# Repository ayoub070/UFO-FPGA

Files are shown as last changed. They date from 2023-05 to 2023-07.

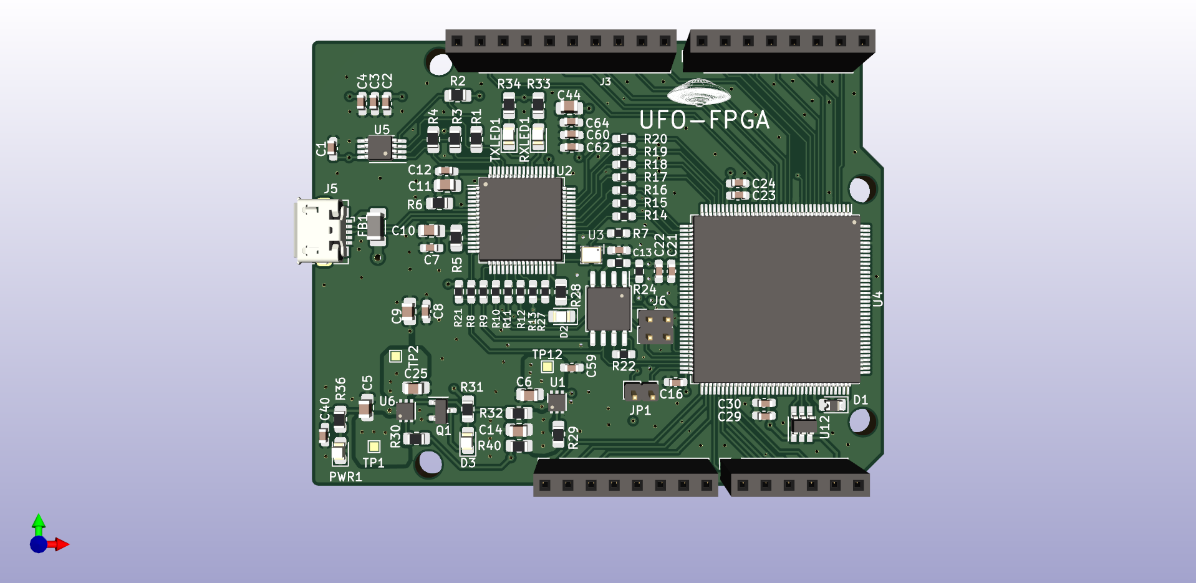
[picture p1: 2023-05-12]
UFO-FPGA/UFO-FPGA-2.png

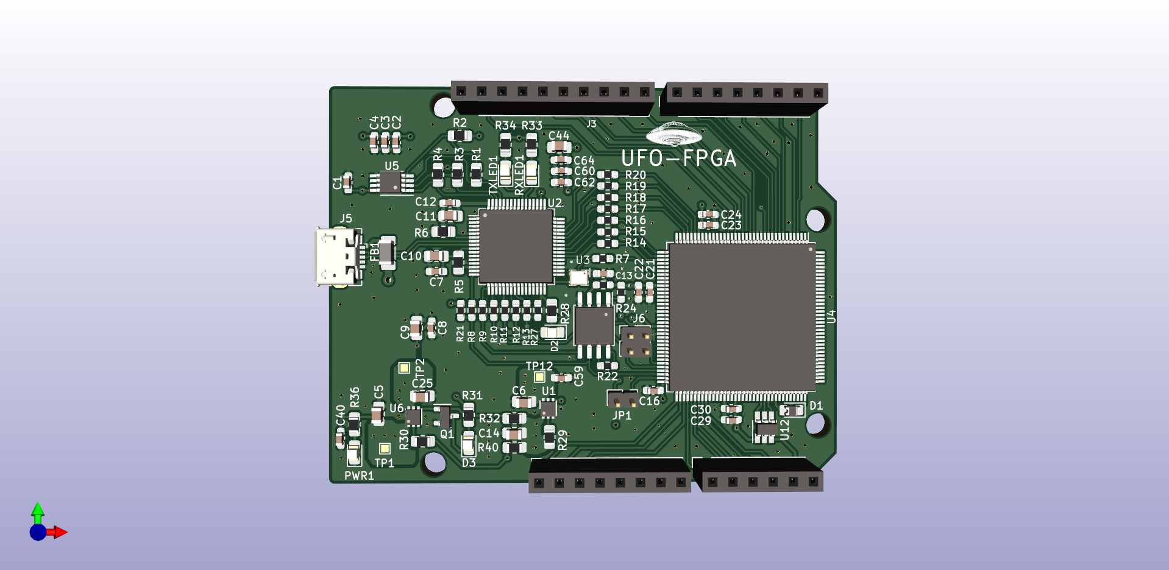
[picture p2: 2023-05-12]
UFO-FPGA/UFO-FPGA.png

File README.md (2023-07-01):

# UFO-FPGA

The UFO-FPGA project is a collaborative effort by students and hobbyists, aimed at promoting and enhancing the excitement of working with Field-Programmable Gate Arrays (FPGAs). 

Our main objective is to develop an FPGA development board that follows the Arduino Uno format, making it easily accessible and familiar to users. The intention behind this project is to foster an open source community where users can contribute and build upon the existing files.

Key Features:
- The board supports communication with the FPGA through UART.
- The FPGA used in this project is the lattice ICE40HX4K, known for its versatility, performance and low power consumption .

Programming Options:
- Users have the flexibility to choose between different programming environments. They can utilize the closed-source ICecube 2 or leverage open source resources like apio (not yet working).

We welcome contributions from anyone interested in joining our mission to inspire students and hobbyists in the world of FPGAs. Feel free to explore the project, experiment with the board, and contribute to its ongoing development.

Please refer to the documentation and resources provided in this repository for detailed instructions on how to get started with the UFO-FPGA project.


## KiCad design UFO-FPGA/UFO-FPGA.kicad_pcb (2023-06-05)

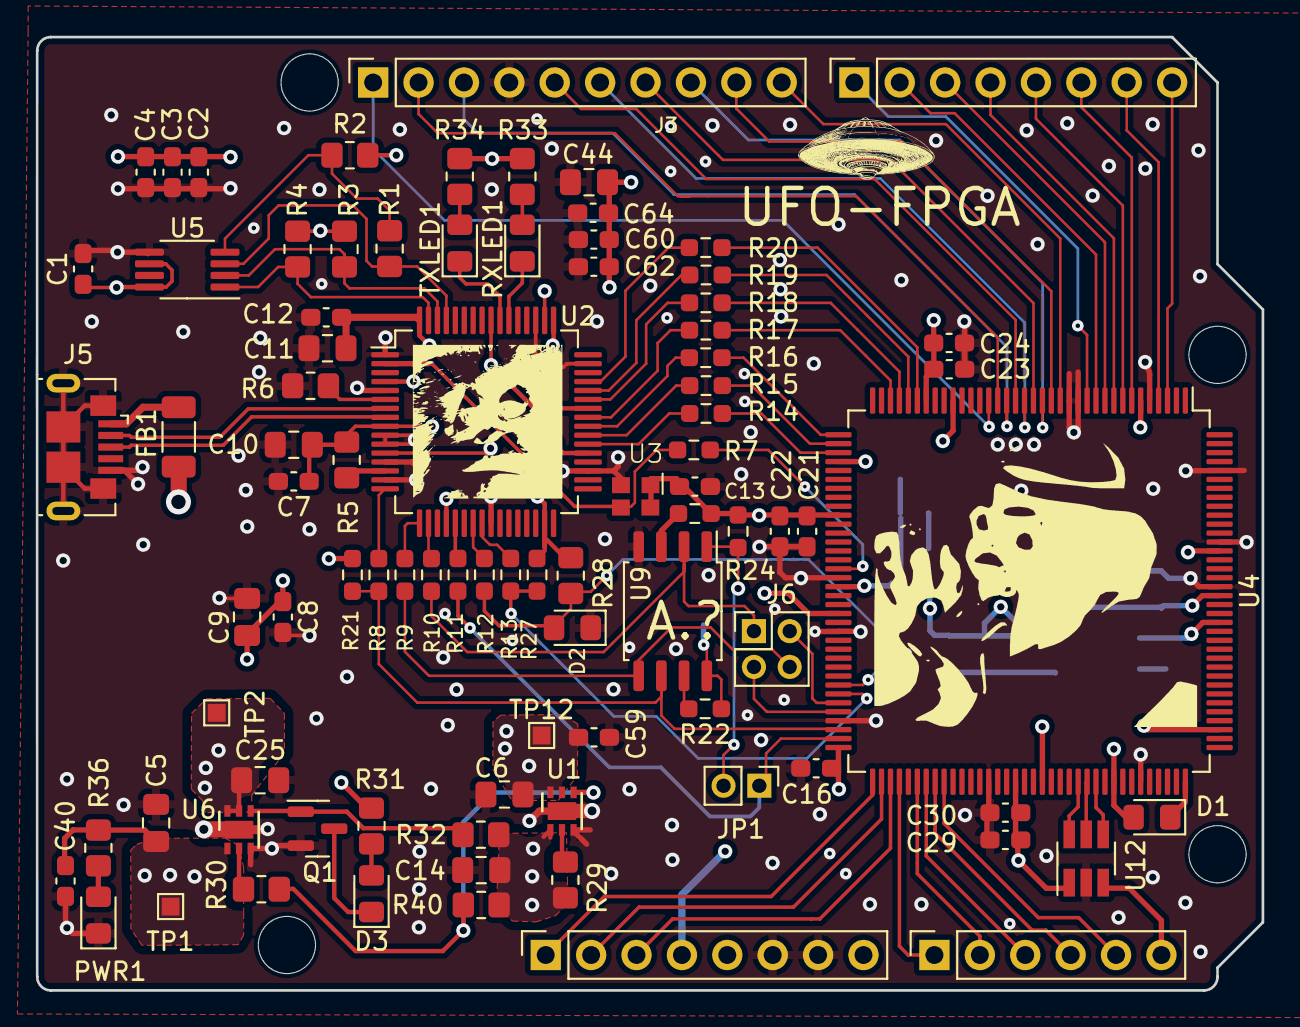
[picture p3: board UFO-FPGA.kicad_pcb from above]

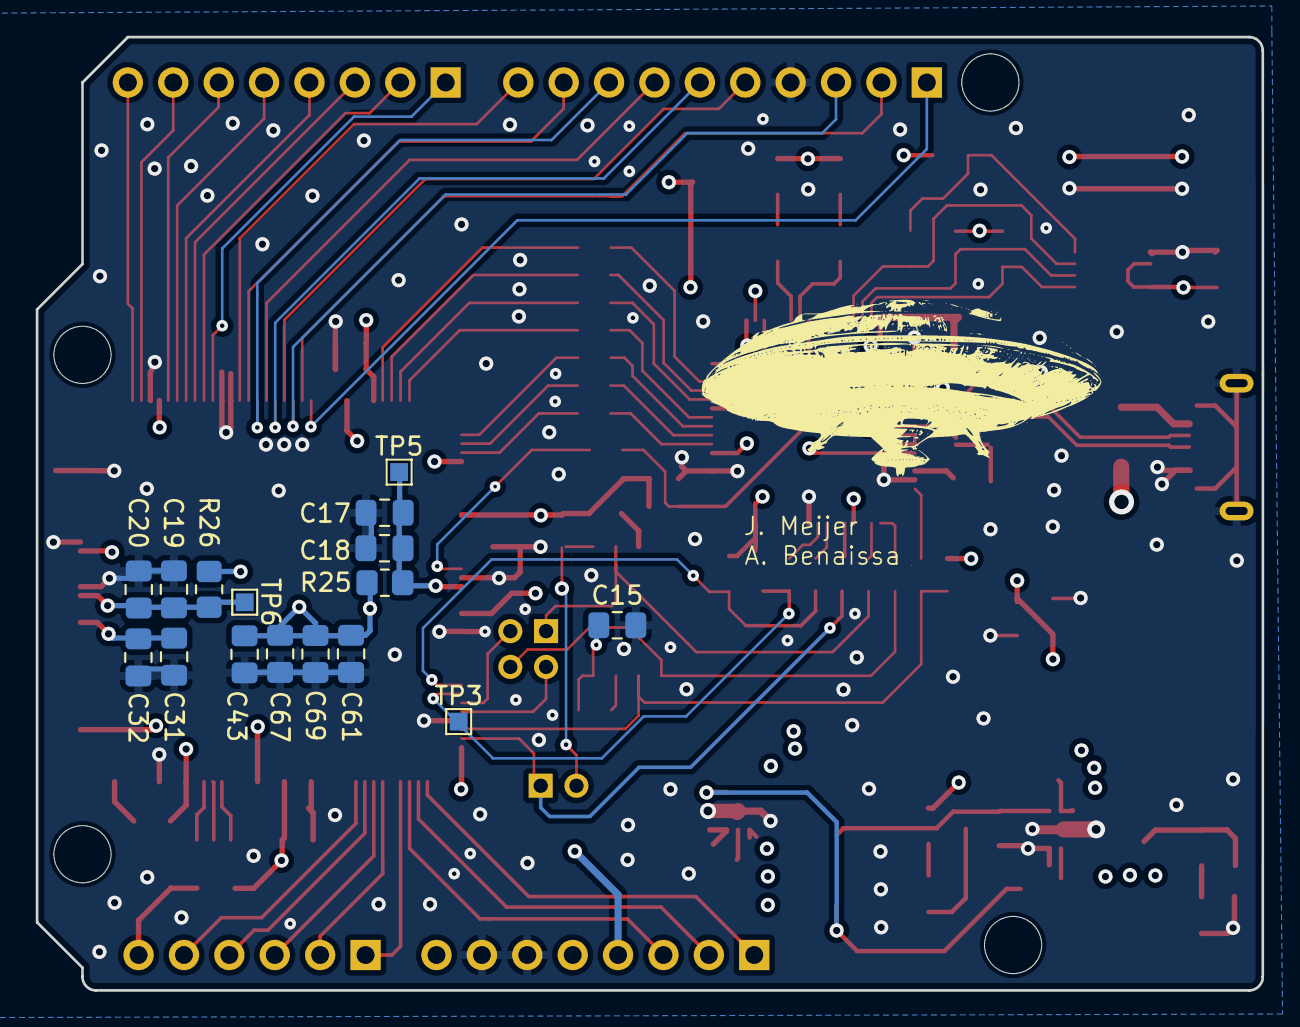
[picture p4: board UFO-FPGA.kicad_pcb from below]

Board: 4 copper layers, 68.6 x 53.3 mm, 108 parts (16 on the bottom side), 90 nets.

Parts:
C1, C7, C8, C12, C13, C16, C40, C62: 100nF; C_0603_1608Metric_Pad1.08x0.95mm_HandSolder
C2, C3, C4, C21, C22, C23, C24, C29, C30: 200nF; C_0603_1608Metric_Pad1.08x0.95mm_HandSolder
C5, C14: 1uF; C_0805_2012Metric_Pad1.18x1.45mm_HandSolder
C6, C11, C18, C19, C25, C43, C44: 10uF; C_0805_2012Metric_Pad1.18x1.45mm_HandSolder
C9, C10: 4u7F; C_0805_2012Metric_Pad1.18x1.45mm_HandSolder
C15, C17, C20: 100nF; C_0805_2012Metric_Pad1.18x1.45mm_HandSolder
C31, C32, C61, C67: 200nF; C_0805_2012Metric_Pad1.18x1.45mm_HandSolder
C59, C60: 1uF; C_0603_1608Metric_Pad1.08x0.95mm_HandSolder
C64: 10nF; C_0603_1608Metric_Pad1.08x0.95mm_HandSolder
C69: 10nF; C_0805_2012Metric_Pad1.18x1.45mm_HandSolder
D1: CDSU4148; D_0805_2012Metric_Pad1.15x1.40mm_HandSolder
D2: GREEN; LED_0805_2012Metric_Pad1.15x1.40mm_HandSolder
D3: POWER; LED_0805_2012Metric_Pad1.15x1.40mm_HandSolder
FB1: 600 Ohm, 500mA; L_1206_3216Metric_Pad1.22x1.90mm_HandSolder
J1: Power; PinSocket_1x08_P2.54mm_Vertical
J2: Digital; PinSocket_1x06_P2.54mm_Vertical
J3: Digital/PWM; PinSocket_1x10_P2.54mm_Vertical
J4: Digital; PinSocket_1x08_P2.54mm_Vertical
J5: USB_B_Micro; USB_Micro-B_GCT_USB3076-30-A
J6: Conn_02x02_Counter_Clockwise; PinHeader_2x02_P2.00mm_Vertical
JP1: Jumper_2_Open; PinHeader_1x02_P2.00mm_Vertical
MH1, MH2, MH3, MH4: MountingHole_3.2mm
PWR1: POWER; LED_0805_2012Metric_Pad1.15x1.40mm_HandSolder
Q1: 2N7002; SOT-23
R1, R5: 2K2; R_0805_2012Metric_Pad1.20x1.40mm_HandSolder
R2, R3, R4: 10K; R_0805_2012Metric_Pad1.20x1.40mm_HandSolder
R6: 12K; R_0805_2012Metric_Pad1.20x1.40mm_HandSolder
R7, R8, R9, R10, R11, R12, R13, R14, R15, R16, R17, R18, R19, R20: 0; R_0603_1608Metric_Pad0.98x0.95mm_HandSolder
R21, R22, R23, R24, R27: 10K; R_0603_1608Metric_Pad0.98x0.95mm_HandSolder
R25, R26: 100; R_0805_2012Metric_Pad1.20x1.40mm_HandSolder
R28: 690R; R_0805_2012Metric_Pad1.20x1.40mm_HandSolder
R29: 0R; R_0805_2012Metric_Pad1.20x1.40mm_HandSolder
R30: 0; R_0805_2012Metric_Pad1.20x1.40mm_HandSolder
R31: 330R; R_0805_2012Metric_Pad1.20x1.40mm_HandSolder
R32, R40: 10k; R_0805_2012Metric_Pad1.20x1.40mm_HandSolder
R33, R34: 220R; R_0805_2012Metric_Pad1.20x1.40mm_HandSolder
R36: 1K; R_0805_2012Metric_Pad1.20x1.40mm_HandSolder
RXLED1: RXLED; LED_0805_2012Metric_Pad1.15x1.40mm_HandSolder
TP1, TP2, TP3, TP5, TP6, TP12: TestPoint; TestPoint_Pad_1.0x1.0mm
TXLED1: TXLED; LED_0805_2012Metric_Pad1.15x1.40mm_HandSolder
U1: NCP187AMT120TAG (+1V2); DFN-6-1EP_2x2mm_P0.65mm_EP1x1.6mm
U2: FT2232HL; LQFP-64_10x10mm_P0.5mm
U3: ASDMB-12MHz; ASDDV-12.000MHz-LC-T3
U4: ICE40HX4K-TQ144; TQFP-144_20x20mm_P0.5mm
U5: 93LC56CT-I/MS; MSOP-8_3x3mm_P0.65mm
U6: NCP187AMT330TAG (+3V3); DFN-6-1EP_2x2mm_P0.65mm_EP1x1.6mm
U9: N25Q032A13ESC40F; SSOP-8_5.25x5.24mm_P1.27mm
U12: MAX11116AUT+T; SOT-23-6_Handsoldering

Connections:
+1V2: C6.1, C43.1, C59.1, C61.1, C67.1, C69.1, R25.2, R26.1, TP12.1, U1.5 (SNS), U1.6 (OUT), U4.27 (VCC), U4.40 (VCC), U4.92 (VCC), U4.111 (VCC)
+1V8: C11.1, C12.1, U2.12 (VCORE), U2.37 (VCORE), U2.49 (VREGOUT), U2.64 (VCORE)
+2V5: D1.1 (K), U4.108 (VPP_2V5)
+3V3: C1.1, C2.1, C3.1, C4.1, C7.1, C8.1, C9.1, C10.1, C13.1, C15.1, C16.1, C21.1, C22.1, C23.1, C24.1, C25.1, C29.1, C30.1, C31.1, C32.1, C44.1, C60.1, C62.1, C64.1, D1.2 (A), J1.4, R2.2, R3.2, R4.2, R5.2, R21.1, R22.1, R23.1, R24.1, R27.1, R28.1, R31.1, R33.2, R34.2, TP2.1, U2.4 (VPHY), U2.9 (VPLL), U2.20 (VCCIO), U2.31 (VCCIO), U2.42 (VCCIO), U2.50 (VREGIN), U2.56 (VCCIO), U3.1 (Standby), U3.4 (VDD), U4.6 (VCCIO_3), U4.30 (VCCIO_3), U4.46 (VCCIO_2), U4.57 (VCCIO_2), U4.72 (VCC_SPI), U4.89 (VCCIO_1), U4.100 (VCCIO_1), U4.123 (VCCIO_0), U4.131 (VCCIO_0), U5.6 (ORG), U5.8 (Vcc), U6.5 (SNS), U6.6 (OUT), U9.8 (Vcc), U12.1 (VDD)
+5V: C5.1, C14.1, C40.1, FB1.1, J1.5, R29.2, R32.2, R36.1, R40.2, TP1.1, U1.1 (IN), U6.1 (IN)
/BANK 4 - SPI Programming/ICE_MISO: J6.2, U4.67 (IOB_105_SDO)
/BANK 4 - SPI Programming/ICE_MOSI: J6.3, U4.68 (IOB_106_SDI)
/BANK 4 - SPI Programming/N25-CS: JP1.2 (B), R24.2, U9.1 (CS)
/BANK 4 - SPI Programming/N25-HOLD: R22.2, U9.7 (HOLD)
/BANK 4 - SPI Programming/N25-WP: R23.2, U9.3 (Wp)
/BANK 4 - SPI Programming/VCCPLL0: C17.1, C18.1, R25.1, TP5.1, U4.54 (VCCPLL0)
/BANK 4 - SPI Programming/VCCPLL1: C19.1, C20.1, R26.2, TP6.1, U4.126 (VCCPLL1)
/POWER/3v3-EN: R30.1, U6.2 (EN)
/POWER/LED-ON: D3.1 (K), Q1.3 (D)
/POWER/PG1V2: R30.2, R40.1, U1.4 (PG)
/POWER/PG3v3: Q1.1 (G), R32.1, U6.4 (PG)
/POWER/RIND-ON: D3.2 (A), R31.2
/USB Programmer/CTSn-ft: R17.1, U2.41 (BDBUS3)
/USB Programmer/DCDn-ft: R20.1, U2.45 (BDBUS6)
/USB Programmer/DSRn-ft: R19.1, U2.44 (BDBUS5)
/USB Programmer/DTRn-ft: R18.2, U2.43 (BDBUS4)
/USB Programmer/EE-CLK: R3.1, U2.62 (EECLK), U5.2 (CLK)
/USB Programmer/EE-CS: R4.1, U2.63 (EECS), U5.1 (CS)
/USB Programmer/EE-D: R1.2, U2.61 (EEDATA), U5.3 (DI)
/USB Programmer/EE-DO: R1.1, R2.1, U5.4 (DO)
/USB Programmer/FLASH_MISO: R10.2, U2.18 (ADBUS2)
/USB Programmer/FLASH_MOSI: R9.2, U2.17 (ADBUS1)
/USB Programmer/FTD-OSCI: R7.1, U2.2 (OSCI), U3.3 (Out)
/USB Programmer/ICE-CDONE: R12.2, U2.23 (ADBUS6)
/USB Programmer/ICE-CREST: R13.2, U2.24 (ADBUS7)
/USB Programmer/ICE-SCK: R8.2, U2.16 (ADBUS0)
/USB Programmer/ICE-SS-B: R11.2, U2.21 (ADBUS4)
/USB Programmer/RS232-Rx-TTL: R14.2, U2.38 (BDBUS0)
/USB Programmer/RS232-Tx-TTL: R15.2, U2.39 (BDBUS1)
/USB Programmer/RTSn-ft: R16.1, U2.40 (BDBUS2)
/USB Programmer/ftd-ref: R6.1, U2.6 (REF)
/USB Programmer/ftd-reset: R5.1, U2.14 (~RESET)
/USB Programmer/rxled out: RXLED1.1 (K), U2.54 (BCBUS3)
/USB Programmer/rxled-mid: R33.1, RXLED1.2 (A)
/USB Programmer/txled out: TXLED1.1 (K), U2.55 (BCBUS4)
/USB Programmer/txled-mid: R34.1, TXLED1.2 (A)
ADC-CS: U4.98 (IOR_148), U12.4 (CS)
AIN1: J2.6, U12.3 (AIN)
CTSn: R17.2, U4.34 (IOL_25B)
D+: J5.3 (D+), U2.8 (DP)
D-: J5.2 (D-), U2.7 (DM)
DCDn: R20.2, U4.31 (IOL_24A)
DSRn: R19.2, U4.32 (IOL_24B)
DTRn: R18.1, U4.33 (IOL_25A)
Flash-MISO: J6.1, R10.1, U9.2 (SDO)
Flash-MOSI: J6.4, R9.1, U9.5 (SDI)
GND: C1.2, C2.2, C3.2, C4.2, C5.2, C6.2, C7.2, C8.2, C9.2, C10.2, C11.2, C12.2, C13.2, C14.2, C15.2, C16.2, C17.2, C18.2, C19.2, C20.2, C21.2, C22.2, C23.2, C24.2, C25.2, C29.2, C30.2, C31.2, C32.2, C40.2, C43.2, C44.2, C59.2, C60.2, C61.2, C62.2, C64.2, C67.2, C69.2, D2.1 (K), J1.6, J1.7, J3.4, J5.5 (GND), J5.6 (Shield), PWR1.1 (K), Q1.2 (S), R6.2, U1.3 (GND), U1.7 (GND), U2.1 (GND), U2.5 (GND), U2.10 (AGND), U2.11 (GND), U2.13 (TEST), U2.15 (GND), U2.25 (GND), U2.35 (GND), U2.47 (GND), U2.51 (GND), U3.2 (GND), U4.5 (GND), U4.13 (GND), U4.14 (GND), U4.53 (GNDPLL0), U4.59 (GND), U4.69 (GND), U4.86 (GND), U4.103 (GND), U4.127 (GNDPLL1), U4.132 (GND), U4.140 (GND), U5.5 (Vss), U6.3 (GND), U6.7 (GND), U9.4 (Vss), U12.2 (GND)
ICE_CDONE: D2.2 (A), R12.1, R28.2, U4.65 (CDONE)
ICE_CLK: R7.2, U4.52 (IOB_82_GBIN4)
ICE_CREST: R13.1, R27.2, TP3.1, U4.66 (~CRESET)
ICE_SCK: R8.1, R21.2, U4.70 (IOB_107_SCK), U9.6 (SCK)
ICE_SS_B: JP1.1 (A), R11.1, U4.71 (IOB_108_SS)
MISO: U4.97 (IOR_147), U12.5 (DOUT)
unnamed: PWR1.2 (A), R36.2
unnamed: R29.1, U1.2 (EN)
PIN-1: J3.1, U4.23 (IOL_17A)
PIN-2: J3.2, U4.22 (IOL_14B)
PIN-3: J3.3, U4.21 (IOL_14A_GBIN6)
PIN-4: J3.5, U4.20 (IOL_13B_GBIN7)
PIN-5: J3.6, U4.19 (IOL_13A)
PIN-6: J3.7, U4.18 (IOL_12B)
PIN-7: J3.8, U4.17 (IOL_12A)
PIN-8: J3.9, U4.16 (IOL_10B)
PIN-9: J3.10, U4.15 (IOL_10A)
PIN-10: J4.1, U4.12 (IOL_8B)
PIN-11: J4.2, U4.11 (IOL_8A)
PIN-12: J4.3, U4.10 (IOL_5B)
PIN-13: J4.4, U4.9 (IOL_5A)
PIN-14: J4.5, U4.8 (IOL_4B)
PIN-15: J4.6, U4.7 (IOL_4A)
PIN-16: J4.7, U4.4 (IOL_3B)
PIN-17: J4.8, U4.3 (IOL_3A)
PIN-18: J2.5, U4.81 (IOR_117)
PIN-19: J2.4, U4.80 (IOR_116)
PIN-20: J2.3, U4.79 (IOR_115)
PIN-21: J2.2, U4.78 (IOR_114)
PIN-22: J2.1, U4.76 (IOR_112)
PIN-23: J1.3, U4.75 (IOR_111)
PIN-24: J1.2, U4.74 (IOR_110)
PIN-25: J1.1, U4.73 (IOR_109)
RS232_Rx_TTL: R14.1, U4.39 (IOB_61)
RS232_Tx_TTL: R15.1, U4.38 (IOB_57)
RTSn: R16.2, U4.37 (IOB_56)
SCK: U4.96 (IOR_146), U12.6 (SCLK)
Vin: FB1.2, J5.1 (VBUS)

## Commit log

2023-04-21 Add files via upload
    Updated to v0.2
    [BANK0.kicad_sch, BANK1.kicad_sch, BANK2.kicad_sch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]
2023-04-21 Moved items
    [BANK4.kicad_sch]
2023-04-21 pinout tab
    [BANK0.kicad_sch, BANK1.kicad_sch, BANK2.kicad_sch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]
2023-04-22 Power schematisch gemaakt
    [POWER.kicad_sch]
2023-04-22 Added net labels
    [BANK0.kicad_sch, BANK1.kicad_sch, BANK2.kicad_sch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]
2023-04-22 Pinout for ADC
2023-04-23 ADC schematic met note's
    [ADC.kicad_sch]
2023-04-23 Labels and schametic changes
    Updated Power schematic
    Added labes for the different nets
    [ADC.kicad_sch, BANK0.kicad_sch, BANK1.kicad_sch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]
2023-04-24 Test van ground enable gedaan en foto toegevoeg
    De enable werkt
    [POWER.kicad_sch]
2023-04-25 Arduino PCB
    Added Arduino PCB format
    [BANK2.kicad_sch, PINOUT.kicad_sch, Programmer.kicad_sch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]
2023-04-25 Fixed text and placement
    [POWER.kicad_sch]
2023-04-25 Dual ramp MC34 inverting converter added
    [UFO-FPGA.kicad_sch, untitled.kicad_sch]
2023-04-25 pins and USB
    [BANK0.kicad_sch, BANK2.kicad_sch, BANK3.kicad_sch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]
2023-04-25 De inverting supply schakeling gemaakt
    [BANK0.kicad_sch, BANK3.kicad_sch, PINOUT.kicad_sch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]
2023-04-25 IO and power
    [BANK0.kicad_sch, BANK1.kicad_sch, BANK2.kicad_sch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]
2023-04-25 Opamp gemaakt van de ADC
    Enkel nog begrijpen wat VDC is. Aan docent vragen?
    [ADC.kicad_sch, BANK0.kicad_sch, BANK1.kicad_sch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]
2023-04-25 PCB and footprint
    Added foorprints and moved on pcb layout
    [ADC.kicad_sch, BANK4.kicad_sch, PINOUT.kicad_sch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]
2023-04-26 edge cuts
    [POWER.kicad_sch, Programmer.kicad_sch, UFO-FPGA.kicad_pcb]
2023-04-26 footprints and PCB
    [BANK0.kicad_sch, BANK1.kicad_sch, BANK2.kicad_sch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]
2023-04-26 Nieuwe ADC conmponent
2023-04-26 Schakeling ADC gemaakt 1 opamp weg gehaald
    [ADC.kicad_sch]
2023-04-26 Weerstanden waardes verandert en namen verandert
    [untitled.kicad_sch]
2023-04-26 Footprints and values
    [ADC.kicad_sch, BANK2.kicad_sch, POWER.kicad_sch]
2023-04-26 Weerstand veranderd Waardoor er minder stroom loopt naar de opamp want er is niet veel stroom nodig
    [untitled.kicad_sch]
2023-04-27 PCB planes
    Added:
    added Power plane +1v2, +3v3 and +5v on layer 4
    Ground plane on layer 2 and 5
    Added signal layer 1,3 and 6
    [ADC.kicad_sch, BANK0.kicad_sch, BANK1.kicad_sch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]
2023-04-27 ubs shield
    [POWER.kicad_sch, UFO-FPGA.kicad_pcb]
2023-04-28 PCB
    many pcb changes
    -started routing
    -added vias
    -power planes
    -ground planes
    [BANK0.kicad_sch, BANK1.kicad_sch, BANK2.kicad_sch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]
2023-04-28 pcb update
    [UFO-FPGA.kicad_pcb]
2023-04-28 DRC run
    [UFO-FPGA.kicad_pcb]
2023-04-29 pcb prog redesign
    [ADC.kicad_sch, BANK2.kicad_sch, BANK3.kicad_sch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]
2023-04-30 pcb placement
    [BANK0.kicad_sch, BANK1.kicad_sch, BANK2.kicad_sch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]
2023-04-30 PCB placement
    spi connected
    [UFO-FPGA.kicad_pcb]
2023-05-01 pcb 0603
    [ADC.kicad_sch, BANK0.kicad_sch, BANK1.kicad_sch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]
2023-05-01 pcb and footprints
    0603
    [Programmer.kicad_sch, UFO-FPGA.kicad_pcb]
2023-05-01 pcb
    added John zendong
    [ADC.kicad_sch, BANK0.kicad_sch, BANK1.kicad_sch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]
2023-05-05 pcb
    added monkey
    [BANK0.kicad_sch, BANK1.kicad_sch, BANK2.kicad_sch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]
2023-05-06 vias and silkscreen
    [UFO-FPGA.kicad_pcb]
2023-05-07 Added UFO
    [UFO-FPGA.kicad_pcb]
2023-05-08 pcb silkscreen
    [BANK0.kicad_sch, BANK1.kicad_sch, BANK2.kicad_sch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]
2023-05-11 monkey 2
    [UFO-FPGA.kicad_pcb]
2023-05-12 3v3 traces
    [UFO-FPGA.kicad_pcb]
2023-05-12 ufo board png
2023-05-12 Wat warnings weg gewerkt gerber file gemaakt met de drill files ze staan in gerber-test
    [UFO-FPGA-B_Cu.gbr, UFO-FPGA-B_Mask.gbr, UFO-FPGA-B_Paste.gbr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]
2023-06-24 Readme geupdate
    Moet nog wel wat technische dingen bij komen maar dit is wel een mooie opzet
2023-07-01 changed gerber name
    [UFO-FPGA-B_Cu.gbr, UFO-FPGA-B_Mask.gbr, UFO-FPGA-B_Paste.gbr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]
2023-07-01 Remove unnessesary
    [Invert-5V-Dual-Ramp.kicad_sch, untitled.kicad_sch]
